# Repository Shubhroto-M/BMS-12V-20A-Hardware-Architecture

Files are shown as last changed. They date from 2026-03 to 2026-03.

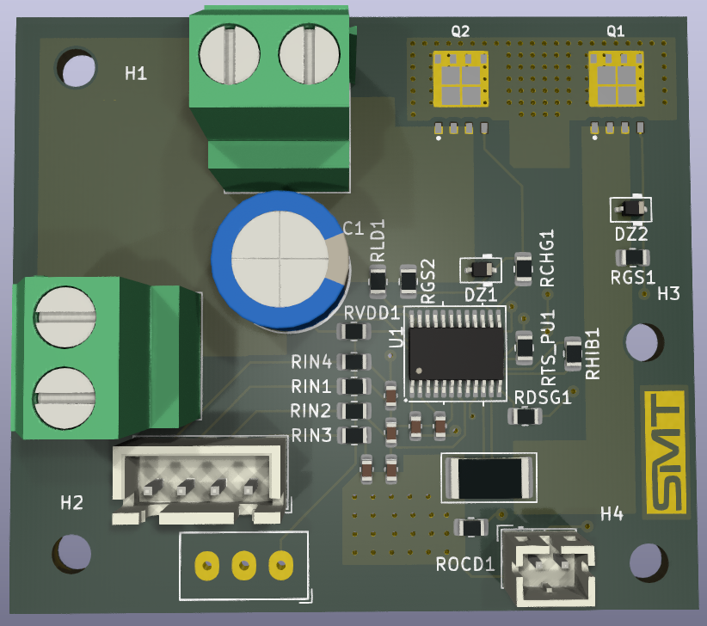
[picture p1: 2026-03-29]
Screenshot 2026-03-29 023947.png

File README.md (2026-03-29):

12V 20A High-Current Battery Management System (BMS)Role: Hardware & Thermal Architecture
Status: V0.2 Blueprint Complete (Validated via Ansys Simulation)

The Objective:

Architected and routed a custom 12V, 20A continuous-draw Battery Management System designed for high-current robotics and electric power applications. The design prioritizes extreme hardware reliability, completely bypassing firmware-dependent microcontrollers in favor of hardware-level fault protection.Core ArchitectureLogic Controller: Texas Instruments BQ77915. Chosen for its standalone, firmware-less hardware protection (Overvoltage, Undervoltage, Overcurrent, and Short-Circuit).Power Gating: Implemented a back-to-back (Source-to-Source) MOSFET topology on the low side. This creates a true bidirectional block, ensuring that charging and discharging paths are completely isolated when a fault state is triggered, preventing body-diode bypass.Transient Protection: Integrated TVS (Transient Voltage Suppression) diodes to armor the board against inductive voltage spikes from motors and reverse-polarity events.The Engineering Challenge: Thermal BottleneckingDuring the initial validation of V0.1, I ran a localized thermal stress test using Ansys Discovery. The simulation revealed a critical failure point under maximum load:Pushing 20 Amps continuously through standard 9.3mΩ SMD MOSFETs generated nearly 4 Watts of localized Joule heating ($I^2R$).Due to the low thermal conductivity of the standard FR4 PCB substrate ($0.3 \text{ W/m·K}$), the heat was unable to dissipate efficiently. The simulation showed theoretical junction temperatures exceeding 595°C—a catastrophic failure state.

The V0.2 Pivot (Solving the Thermal Crisis)Rather than increasing the PCB footprint to accommodate bulky, expensive aluminum heatsinks, I re-engineered the power path at the silicon level.Component Swap: Replaced the generic silicon with premium Infineon BSC010N04LS MOSFETs featuring an ultra-low $R_{DS(on)}$ of 1.0mΩ.The Result: This pivot reduced localized heat generation by nearly 90% (dropping from ~4W down to 0.4W per chip).Final Validation: Rerunning the Ansys simulation with a targeted 0.5mm local fidelity mesh confirmed the fix. The concentrated heat was entirely eliminated, allowing the custom copper pours to passively dissipate the remaining thermal load into the ambient air, peaking at a completely safe 60°C under maximum continuous draw.

Industrial Design & EnclosureTo complete the hardware package, I designed a custom, manufacturable 3D enclosure in Fusion 360. The casing features precision IO cutouts for the high-current screw terminals and JST balancing leads, ensuring a flush fit and mechanical strain relief for the PCB.

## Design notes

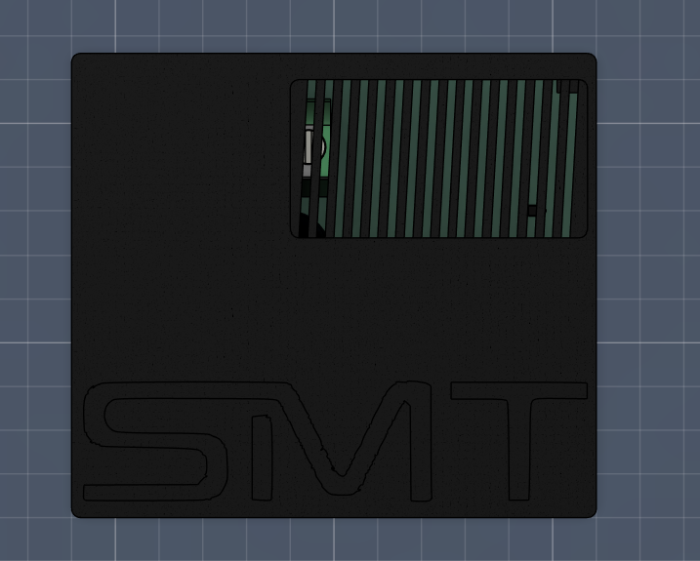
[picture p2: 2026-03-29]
Screenshot 2026-03-29 182541 - Copy.png

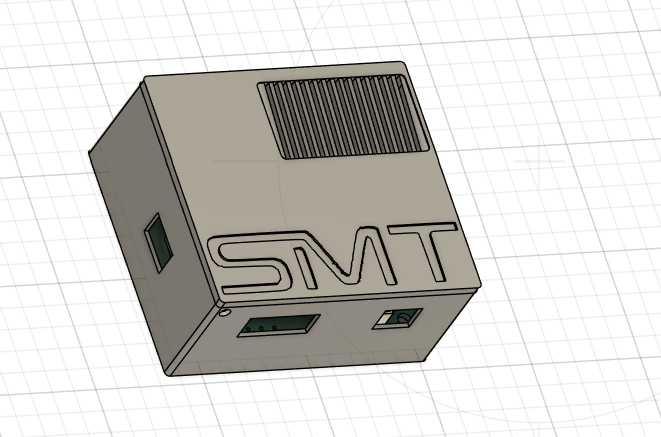
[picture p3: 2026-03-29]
Screenshot 2026-03-29 175812.png

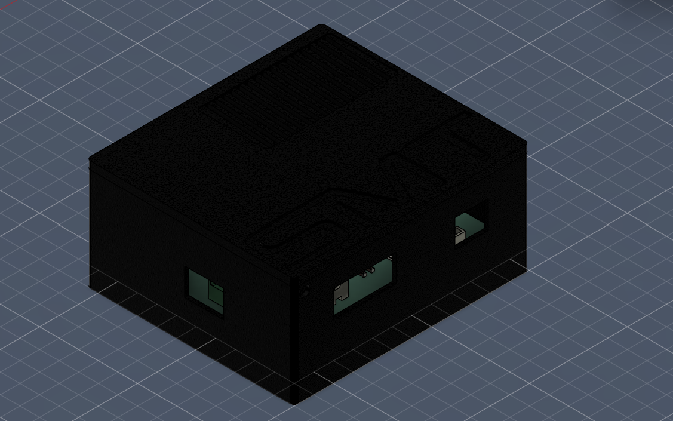
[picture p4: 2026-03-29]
Screenshot 2026-03-29 182611 - Copy.png

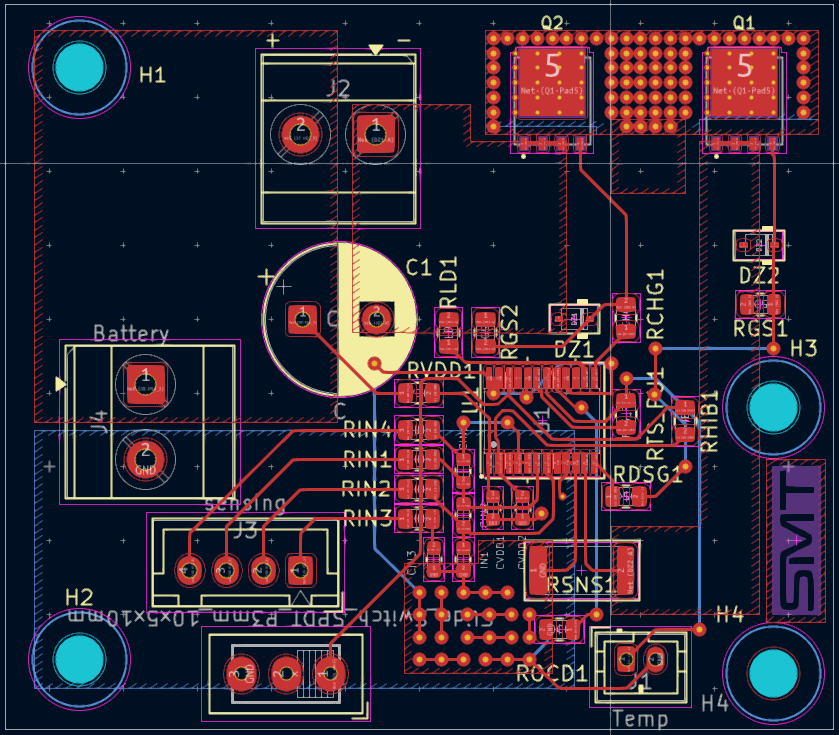
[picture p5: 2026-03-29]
Screenshot 2026-03-29 023929.png

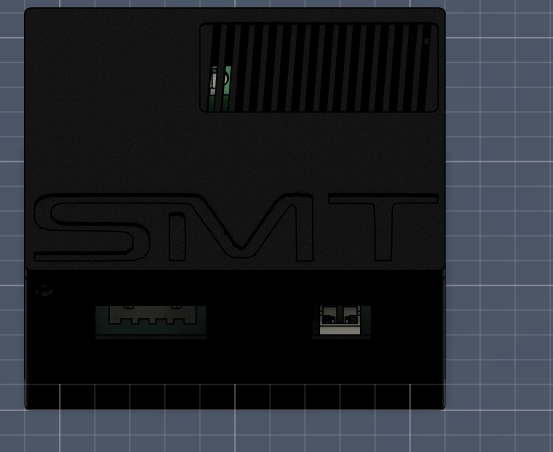
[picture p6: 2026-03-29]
Screenshot 2026-03-29 182556.png

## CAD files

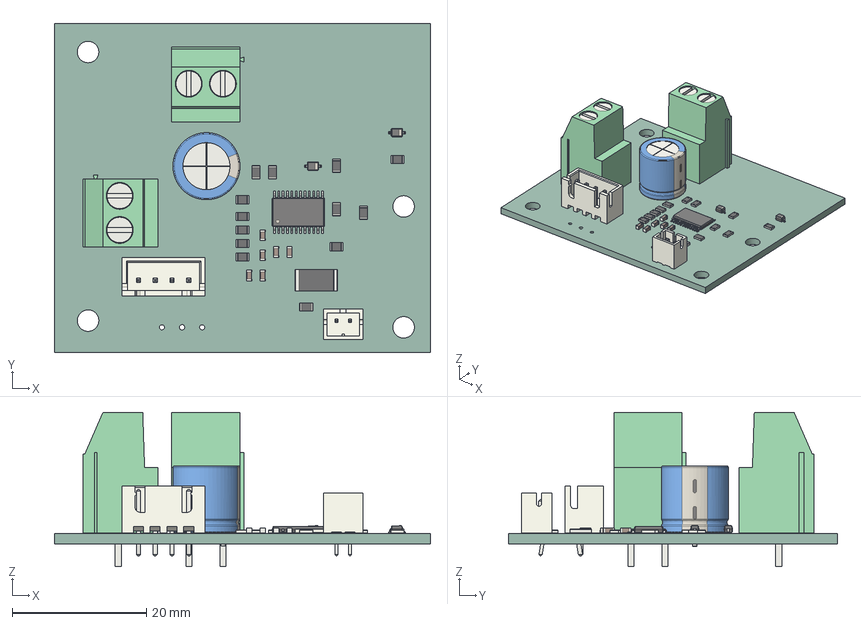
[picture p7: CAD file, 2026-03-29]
BMS_REV_LIGHT_1.step
56.0 x 49.0 x 23.0 mm
R_2512_6332Metric
R_0805_2012Metric x 13
TerminalBlock_Phoenix_MKDS-3-2-5.08_1x02_P5.08mm_Horizontal x 2
C_0603_1608Metric x 6
D_SOD-323 x 2
CP_Radial_D10.0mm_P5.00mm
JST_XH_B4B-XH-A_1x04_P2.50mm_Vertical
JST_PH_B2B-PH-K_1x02_P2.00mm_Vertical
TSSOP-24_4.4x7.8mm_P0.65mm
BMS_REV_1_PCB

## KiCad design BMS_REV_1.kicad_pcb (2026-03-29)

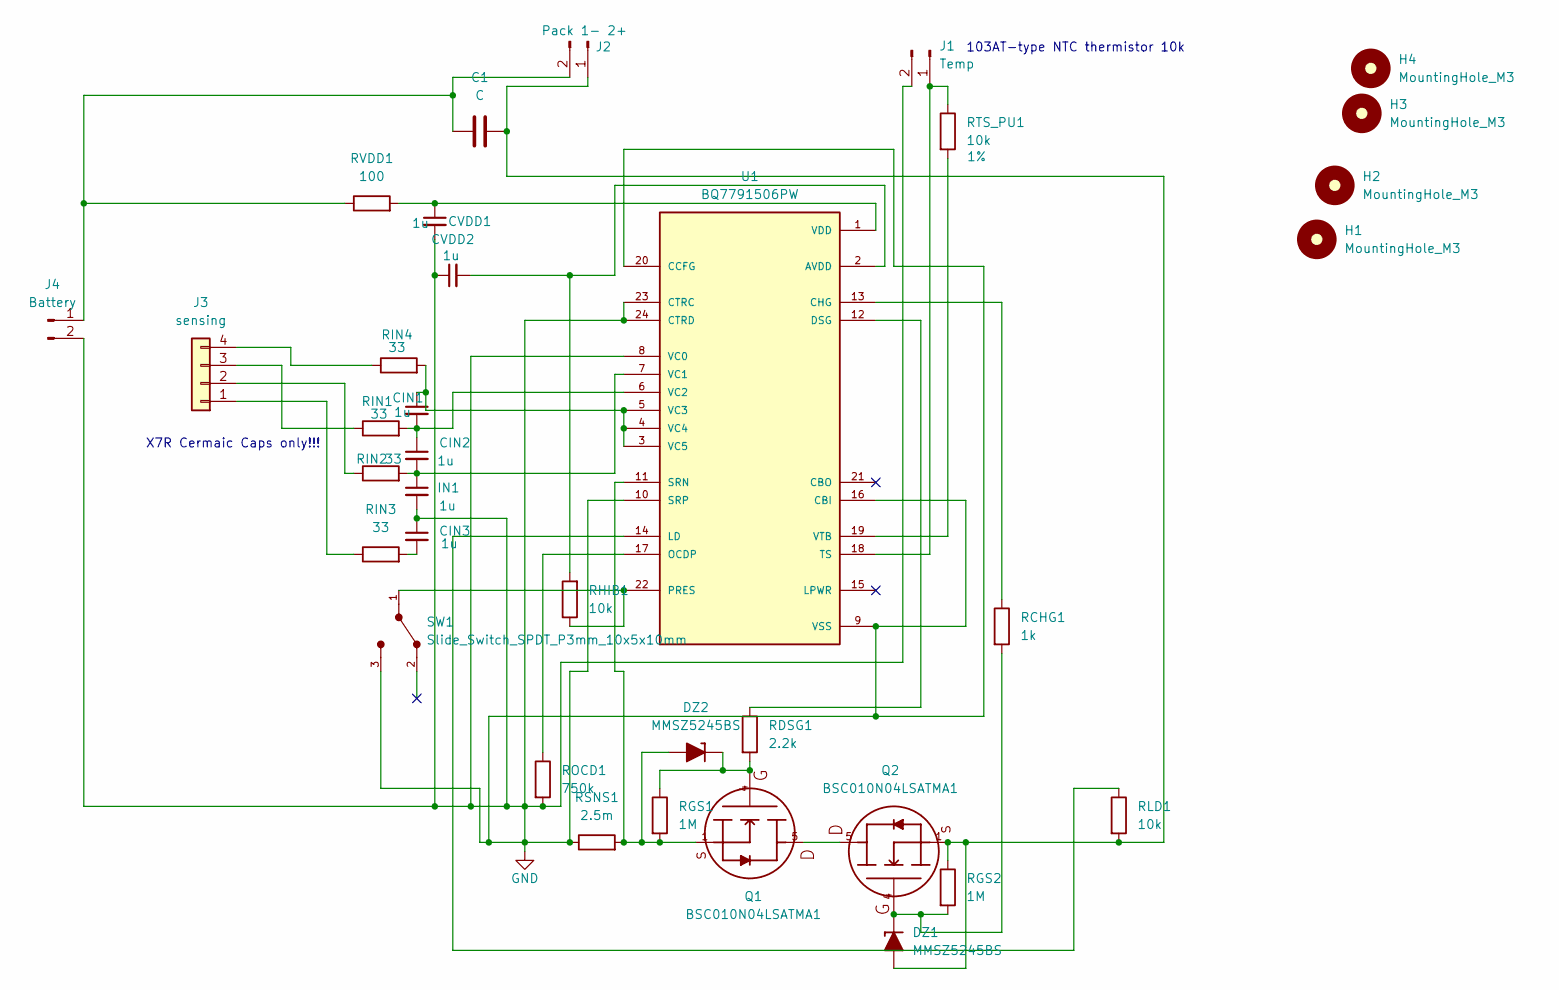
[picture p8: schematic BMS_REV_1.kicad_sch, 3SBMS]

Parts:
C1: C; CP_Radial_D10.0mm_P5.00mm
CIN1, CIN2, CIN3: 1u; C_0603_1608Metric; Voltage 1kV; Tolerance 100%
CVDD1, CVDD2: 1u; C_0603_1608Metric; Voltage 1kV; Tolerance 100%
DZ1, DZ2: MMSZ5245BS; D_SOD-323
H1, H2, H3, H4: MountingHole_M3; MountingHole_3.2mm_M3
IN1: 1u; C_0603_1608Metric; Voltage 1kV; Tolerance 100%
J1: Temp; JST_PH_B2B-PH-K_1x02_P2.00mm_Vertical
J2: Pack 1- 2+; TerminalBlock_Phoenix_MKDS-3-2-5.08_1x02_P5.08mm_Horizontal
J3: sensing; JST_XH_B4B-XH-A_1x04_P2.50mm_Vertical; Part Number 1-0401FBV0T
J4: Battery; TerminalBlock_Phoenix_MKDS-3-2-5.08_1x02_P5.08mm_Horizontal
Q1, Q2: BSC010N04LSATMA1; MOSFET_BSC093N04LSGATMA1
RCHG1: 1k; R_0805_2012Metric
RDSG1: 2.2k; R_0805_2012Metric
RGS1, RGS2: 1M; R_0805_2012Metric
RHIB1: 10k; R_0805_2012Metric
RIN1, RIN2, RIN3, RIN4: 33; R_0805_2012Metric
RLD1: 10k; R_0805_2012Metric
ROCD1: 750k; R_0805_2012Metric
RSNS1: 2.5m; R_2512_6332Metric
RTS_PU1: 10k; R_0805_2012Metric; Tolerance 1%
RVDD1: 100; R_0805_2012Metric
SW1: Slide_Switch_SPDT_P3mm_10x5x10mm
U1: BQ7791506PW; TSSOP-24_4.4x7.8mm_P0.65mm; PARTREV H; DigiKey_Part_Number 296-BQ7791506PW-ND

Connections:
GND: CIN3.1, CVDD1.2, CVDD2.1, IN1.2, J1.2, J4.2, ROCD1.2, RSNS1.1, SW1.3, U1.8 (VC0), U1.9 (VSS), U1.10 (SRP), U1.16 (CBI), U1.20 (CCFG), U1.23 (CTRC), U1.24 (CTRD)
unnamed: CIN3.2, RIN3.2
unnamed: C1.2, DZ1.2 (A), J2.1, Q2.1, Q2.2, Q2.3, RGS2.1, RLD1.2
unnamed: DZ1.1 (K), Q2.4, RCHG1.2, RGS2.2
unnamed: DZ2.2 (A), Q1.1, Q1.2, Q1.3, RGS1.2, RSNS1.2, U1.11 (SRN)
unnamed: DZ2.1 (K), Q1.4, RDSG1.2, RGS1.1
unnamed: J1.1, RTS_PU1.1, U1.18 (TS)
unnamed: C1.1, J2.2, J4.1, RVDD1.1
unnamed: J3.1, RIN3.1
unnamed: J3.2, RIN2.1
unnamed: J3.3, RIN1.1
unnamed: J3.4, RIN4.1
unnamed: Q1.5, Q2.5
unnamed: CVDD2.2, RHIB1.2, U1.2 (AVDD)
unnamed: RCHG1.1, U1.13 (CHG)
unnamed: RDSG1.1, U1.12 (DSG)
unnamed: RLD1.1, U1.14 (LD)
unnamed: ROCD1.1, U1.17 (OCDP)
unnamed: RHIB1.1, SW1.1, U1.22 (PRES)
unnamed: CIN2.2, IN1.1, RIN2.2, U1.7 (VC1)
unnamed: CIN1.2, CIN2.1, RIN1.2, U1.6 (VC2)
unnamed: CIN1.1, RIN4.2, U1.3 (VC5), U1.4 (VC4), U1.5 (VC3)
unnamed: CVDD1.1, RVDD1.2, U1.1 (VDD)
unnamed: RTS_PU1.2, U1.19 (VTB)

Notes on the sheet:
X7R Cermaic Caps only!!!
103AT-type NTC thermistor 10k

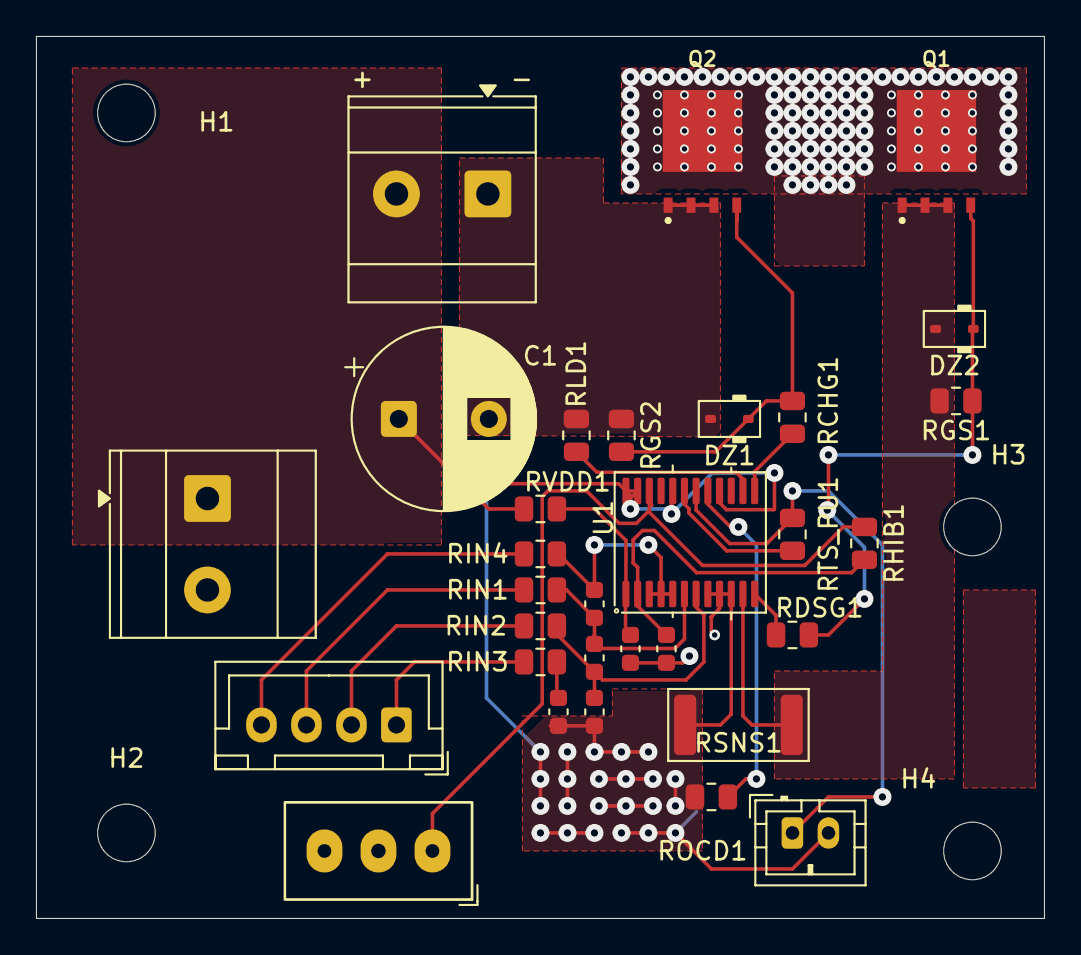
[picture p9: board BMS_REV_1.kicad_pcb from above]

Board: 2 copper layers, 56.0 x 49.0 mm, 35 parts (0 on the bottom side), 24 nets.
